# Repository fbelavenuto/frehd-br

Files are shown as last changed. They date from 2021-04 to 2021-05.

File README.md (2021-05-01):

# TRS-80 FreHD BR version

### English

FreHD is a HD emulator for TRS-80 classic computer.

This board is my version made in Cadsoft Eagle software. Original project:

http://members.iinet.net.au/~ianmav/trs80/emulator.htm

`FreHD` is the project itself, `CP300_Adapter` is for Brazilian TRS-80 Model III clone

### Português

FreHD é um emulador de HD para computadores TRS-80.

Estas placas são uma versão minha feito no software Autodesk Eagle. Projeto original:

http://members.iinet.net.au/~ianmav/trs80/emulator.htm

`FreHD` é o projeto em si, `CP300_Adapter` é para o clone brasileiro TRS-80 model III.

Este projeto utiliza um microcontrolador PIC que deve ser gravado com o firmware do arquivo `FreHD_213.hex` e utiliza um circuito integrado de lógica programável (GAL) que deve ser gravado com o arquivo `gal16v8.jed`.

Para o clone CP500 é necessário a regravação da EPROM interna ou troca com o conteúdo do arquivo `CP500_FreHD.rom`.

Para o CP300 é necessário a construção do adaptador que contém uma EPROM que deve ser gravada com o conteúdo do arquivo `FreHD(3000).bin`. A EPROM utilizada é a 2732 que tem espaço para 4KBytes de dados, por ser mais fácil de se encontrar. O arquivo contém somente 2KBytes de dados e deve ser gravado no começo da EPROM (offset 0) deixando o restante da EPROM sem conteúdo.

A lista de material pode ser encontrada em formato Markdown na pasta *Doc* de cada projeto.

É necessário a confecção de um cabo multivias com 50 vias/conector 2x25 para ligação entre o FreHD e Micro (ou Adaptador) e um cabo multivias de 34 vias/conector 2x17 para a ligação do adaptador no CP300. O cabo de 50 vias pode ser aproveitado de antigos cabos SCSI e para o cabo de 34 vias pode ser aproveitado cabos de floppy sem a torção.

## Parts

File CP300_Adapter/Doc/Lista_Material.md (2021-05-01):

# Lista de material

## Resistores

Todos são de 1/4W

| Qtde | Valor |
|:----:|---|
| 3 | 220Ω |
| 5 | 330Ω |
| 5 | 4K7 |
| 5 | 10K |

## Capacitores

| Qtde | Valor | Tipo | Obs |
|:----:|---|---|-----|
|  2 | 22p | Cerâmico | |
|  3 | 100n | Cerâmico | |
|  5 | 1u/16V  | Eletrolítico | Necessário somente se for utilizar a porta RS-232 |
|  2 | 10u/10V | Eletrolítico | |

## LEDs

| Qtde | Valor |
|:----:|---|
| 1 | 3mm Vermelho |
| 1 | 3mm Verde |

## Transistores

| Qtde | Valor |
|:----:|---|
| 1 | BS170 |

## Circuitos Integrados

Todos os CIs tem emcapsulamento DIP

| Qtde | Valor | Obs |
|:----:|---|-----|
| 1 | PIC18F4680 | Gravar com arquivo [HEX](FreHD_213.hex) |
| 1 | GAL16V8 | Gravar com arquivo [JED](gal16v8.jed) |
| 1 | 74HCT245 | |
| 1 | 74HCT595 | |
| 1 | MAX232 | Necessário somente se for utilizar a porta RS-232 |
| 1 | DS1307 | |
| 1 | LP2950-3V3 | |

## Soquetes (opcional)

| Qtde | Tipo |
|:----:|---|
| 1 | 40 pinos |
| 2 | 20 pinos |
| 2 | 16 pinos |
| 1 | 4 pinos |

## Cristais

| Qtde | Valor | Encapsulamento |
|:----:|---|---|
| 1 | 32,768KHz | TC26V |
| 1 | 10Mhz | HC49U-V |

## Diversos

| Qtde | Valor | Modelo |
|:----:|---|---|
| 1 | Conector Mini-USB (tipo B) | |
| 1 | Conector Pinheader macho 2x25 | |
| 2 | Conector Pinheader macho 1x5 | |
| 1 | Conector para bateria CR2032 | |
| 1 | Conector SD ou micro-SD | |

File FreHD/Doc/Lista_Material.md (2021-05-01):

# Lista de material

## Capacitores

| Qtde | Valor | Tipo |
|:----:|---|---|
|  2 | 100n | Cerâmico |

## Circuitos Integrados

Todos os CIs tem emcapsulamento DIP

| Qtde | Valor | Obs |
|:----:|---|-----|
| 1 | EPROM 2732 | Gravar com arquivo [BIN](FreHD(3000).bin) |
| 1 | 74LS04 | |
## Soquetes (opcional)

| Qtde | Tipo |
|:----:|---|
| 1 | 24 pinos (largo) |
| 1 | 14 pinos |

## Diversos

| Qtde | Valor | Modelo |
|:----:|---|---|
| 1 | Conector Pinheader macho 2x25 | |
| 1 | Conector Pinheader macho 2x17 | |

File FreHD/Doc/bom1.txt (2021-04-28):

Part Value       Device          Package      Description

U1   PIC18F4620  PIC18F4680      PDIP-40
U2   GAL16V8     ATF16V8BP3      DIL20        High perfomance CMOS (electrically erasable) programmable logic device (PLD)
U3   74HCT245N   74HCT245N       DIL20        Octal BUS TRANSCEIVER, 3-state
U5   MAX232      MAX232PTH       DIL16        RS232 Transceiver
U6   74HC595N    74HC595N        DIL16        8-bit SHIFT REGISTER, output latch
U7   DS1307      DS1307          DIL08        DS1307
IC1  LP2950-3V3  LP2950Z         TO92         100 mA, Low Power Low Dropout Voltage Regulator
Q1   BS170       BS170           SOT54E       N-CHANNEL MOS FET
J1   MICROSD     MICROSD         MICROSD      Micro SD Socket (optional)
J2   SDMMC06132  SDMMC06132      06132        SD MMC Card holder
XT1  32.768KHz   CRYSTALTC26V    TC26V        CRYSTAL
XT2  10MHz       CRYSTALHC49U-V  HC49U-V      CRYSTAL
B1   CR2032H     CR2032H         CR2032H      LI BATTERY Varta
C1   100n        C-EU050-024X044 C050-024X044 CAPACITOR, European symbol
C2   22p         C-EU050-024X044 C050-024X044 CAPACITOR, European symbol
C3   22p         C-EU050-024X044 C050-024X044 CAPACITOR, European symbol
C4   100n        C-EU050-024X044 C050-024X044 CAPACITOR, European symbol
C5   10u         CPOL-EUE2-4     E2-4         POLARIZED CAPACITOR, European symbol
C6   1u          CPOL-EUE2-4     E2-4         POLARIZED CAPACITOR, European symbol
C7   1u          CPOL-EUE2-4     E2-4         POLARIZED CAPACITOR, European symbol
C8   1u          CPOL-EUE2-4     E2-4         POLARIZED CAPACITOR, European symbol
C9   100n        C-EU050-024X044 C050-024X044 CAPACITOR, European symbol
C10  1u          CPOL-EUE2-4     E2-4         POLARIZED CAPACITOR, European symbol
C11  1u          CPOL-EUE2-4     E2-4         POLARIZED CAPACITOR, European symbol
C12  10u         CPOL-EUE2-4     E2-4         POLARIZED CAPACITOR, European symbol
R1   4K7         R-EU_0207/10    0207/10      RESISTOR, European symbol
R2   10K         R-EU_0207/10    0207/10      RESISTOR, European symbol
R3   4K7         R-EU_0207/10    0207/10      RESISTOR, European symbol
R4   10K         R-EU_0207/10    0207/10      RESISTOR, European symbol
R5   10K         R-EU_0207/10    0207/10      RESISTOR, European symbol
R6   330         R-EU_0207/10    0207/10      RESISTOR, European symbol
R7   220         R-EU_0207/10    0207/10      RESISTOR, European symbol
R8   330         R-EU_0207/10    0207/10      RESISTOR, European symbol
R9   220         R-EU_0207/10    0207/10      RESISTOR, European symbol
R10  220         R-EU_0207/10    0207/10      RESISTOR, European symbol
R11  330         R-EU_0207/10    0207/10      RESISTOR, European symbol
R12  10K         R-EU_0207/10    0207/10      RESISTOR, European symbol
R13  330         R-EU_0207/10    0207/10      RESISTOR, European symbol
R14  330         R-EU_0207/10    0207/10      RESISTOR, European symbol
R15  10K         R-EU_0207/10    0207/10      RESISTOR, European symbol
R16  4K7         R-EU_0207/10    0207/10      RESISTOR, European symbol
R17  4K7         R-EU_0207/10    0207/10      RESISTOR, European symbol
R18  4K7         R-EU_0207/10    0207/10      RESISTOR, European symbol
X1   MUSB-B      MiniUSB type B  M-USB B      Mini USB type B connector
JP1  BUS         PINHD-2X25      2X25         PIN HEADER
SV1  Serial      MA05-1          MA05-1       PIN HEADER
SV2  ICSP        MA05-1          MA05-1       PIN HEADER
LED1 VM          LED3MM          LED3MM       LED Red 3mm
LED2 VD          LED3MM          LED3MM       LED Green 3mm

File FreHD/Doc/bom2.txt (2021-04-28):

Qty Value       Device          Package      Parts                 Description

1   PIC18F4620  PIC18F4680      PDIP-40      U1
1   GAL16V8     ATF16V8BP3      DIL20        U2                    High perfomance CMOS (electrically erasable) programmable logic device (PLD)
1   74HCT245N   74HCT245N       DIL20        U3                    Octal BUS TRANSCEIVER, 3-state
1   MAX232      MAX232PTH       DIL16        U5                    RS232 Transceiver
1   74HC595N    74HC595N        DIL16        U6                    8-bit SHIFT REGISTER, output latch
1   DS1307      DS1307          DIL08        U7                    DS1307
1   LP2950-3V3  LP2950Z         TO92         IC1                   100 mA, Low Power Low Dropout Voltage Regulator
1   BS170       BS170           SOT54E       Q1                    N-CHANNEL MOS FET
1   MICROSD     MICROSD         MICROSD      J1                    Micro SD Socket (optional)
1   SDMMC06132  SDMMC06132      06132        J2                    SD MMC Card holder
1   32.768KHz   CRYSTALTC26V    TC26V        XT1                   CRYSTAL
1   10MHz       CRYSTALHC49U-V  HC49U-V      XT2                   CRYSTAL
1   CR2032H     CR2032H         CR2032H      B1                    LI BATTERY Varta
3   100n        C-EU050-024X044 C050-024X044 C1, C4, C9            CAPACITOR, European symbol
2   22p         C-EU050-024X044 C050-024X044 C2, C3                CAPACITOR, European symbol
2   10u         CPOL-EUE2-4     E2-4         C5, C12               POLARIZED CAPACITOR, European symbol
5   1u          CPOL-EUE2-4     E2-4         C6, C7, C8, C10, C11  POLARIZED CAPACITOR, European symbol
5   4K7         R-EU_0207/10    0207/10      R1, R3, R16, R17, R18 RESISTOR, European symbol
5   10K         R-EU_0207/10    0207/10      R2, R4, R5, R12, R15  RESISTOR, European symbol
5   330         R-EU_0207/10    0207/10      R6, R8, R11, R13, R14 RESISTOR, European symbol
3   220         R-EU_0207/10    0207/10      R7, R9, R10           RESISTOR, European symbol
1   MUSB-B      MiniUSB type B  M-USB B      X1                    Mini USB type B connector
1   BUS         PINHD-2X25      2X25         JP1                   PIN HEADER
1   ICSP        MA05-1          MA05-1       SV2                   PIN HEADER
1   Serial      MA05-1          MA05-1       SV1                   PIN HEADER
1   VM          LED3MM          LED3MM       LED1                  LED Red 3mm
1   VD          LED3MM          LED3MM       LED2                  LED Green 3mm

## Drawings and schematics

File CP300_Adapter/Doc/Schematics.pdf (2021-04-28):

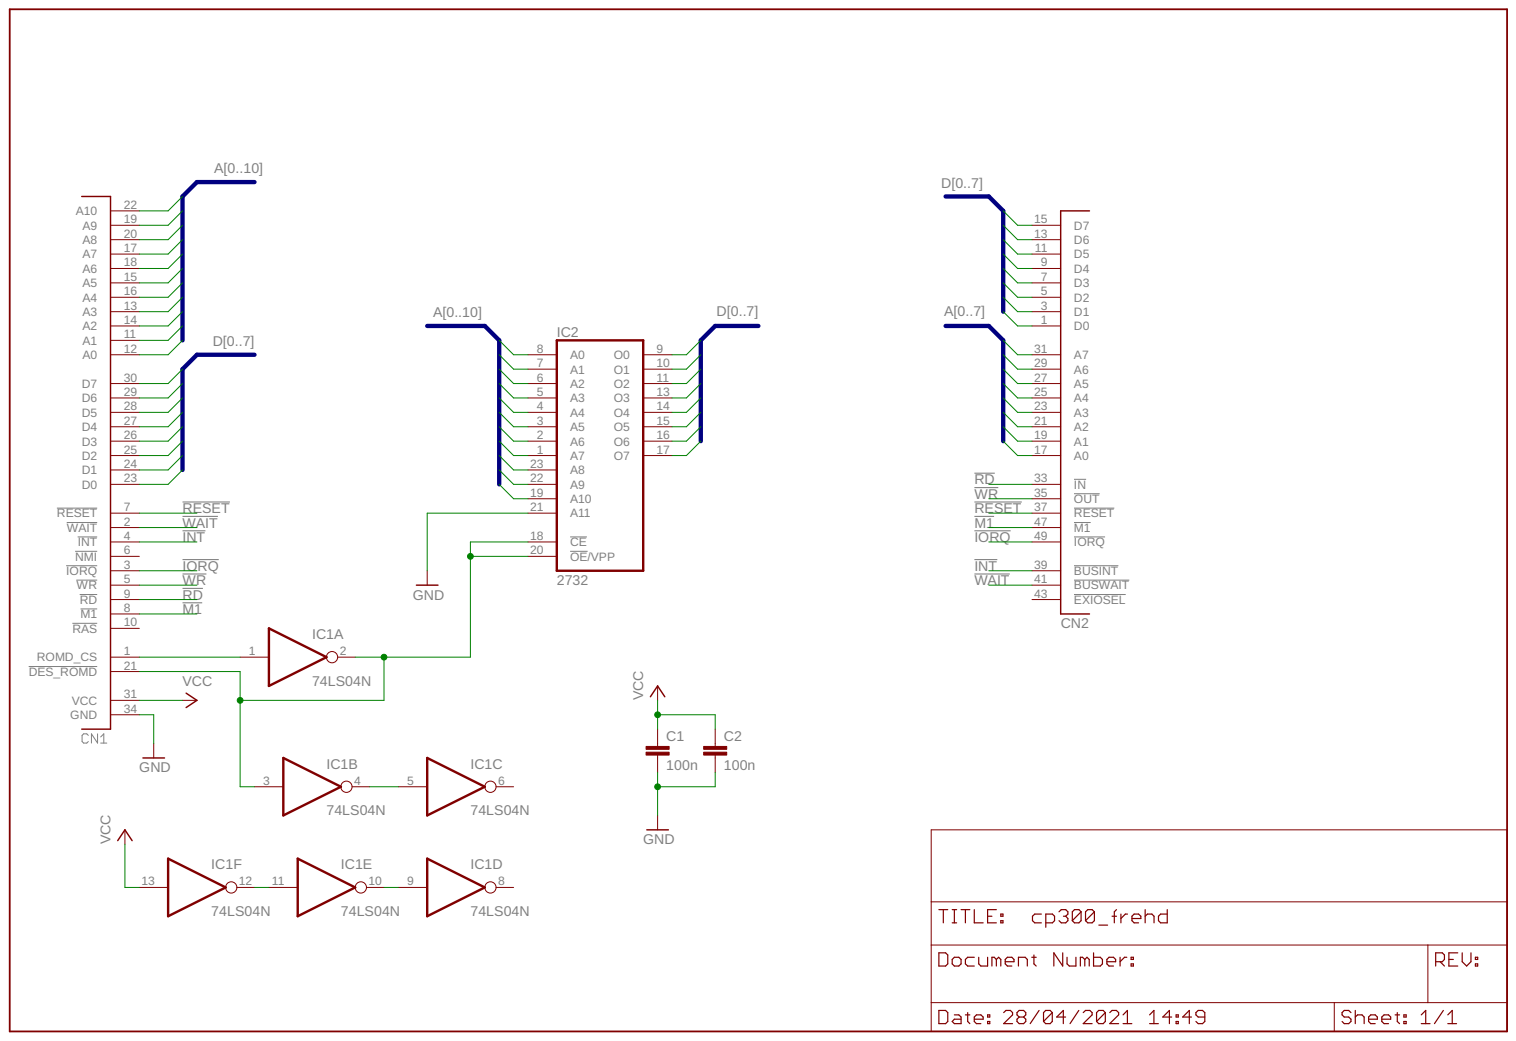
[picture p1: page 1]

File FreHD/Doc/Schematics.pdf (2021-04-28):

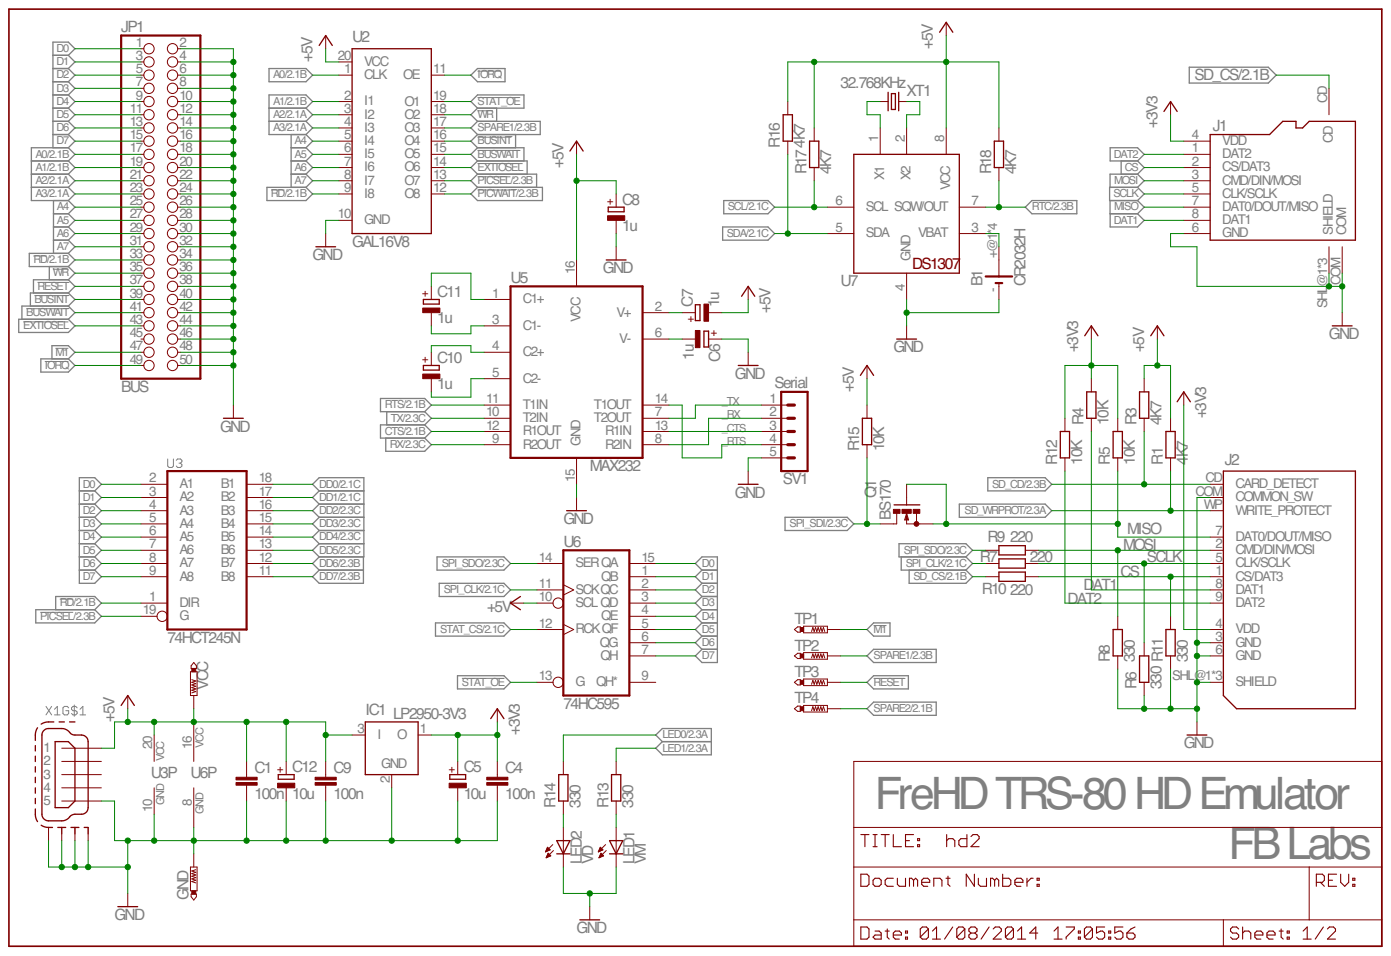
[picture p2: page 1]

13 | 3 _CTS

_RTS 4

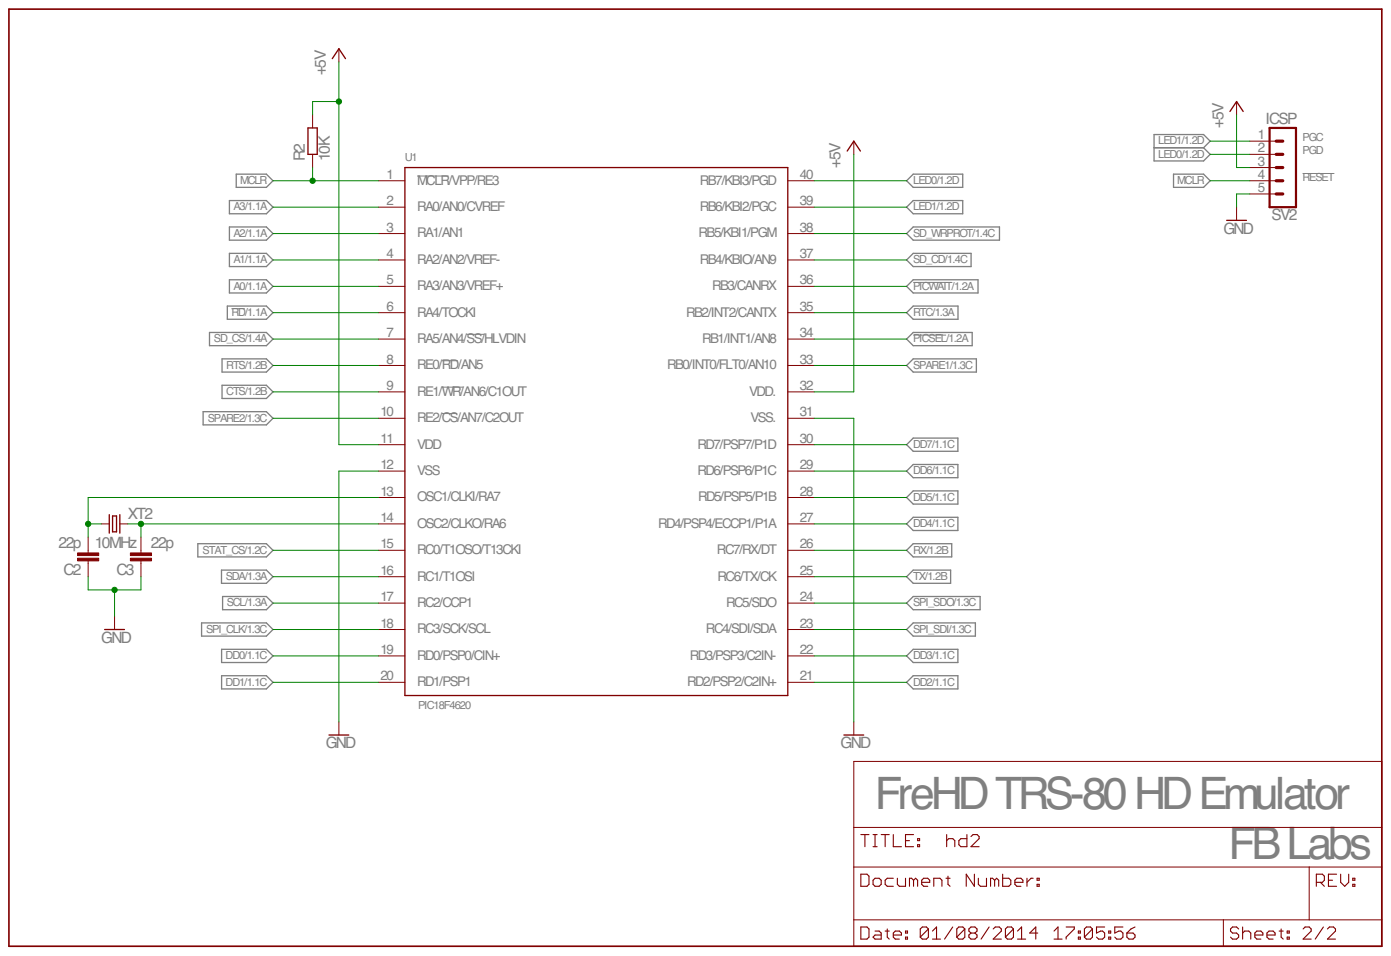
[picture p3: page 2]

RC0/T1OSO/T13CKI 15 RC1/T1OSI 16 | 26

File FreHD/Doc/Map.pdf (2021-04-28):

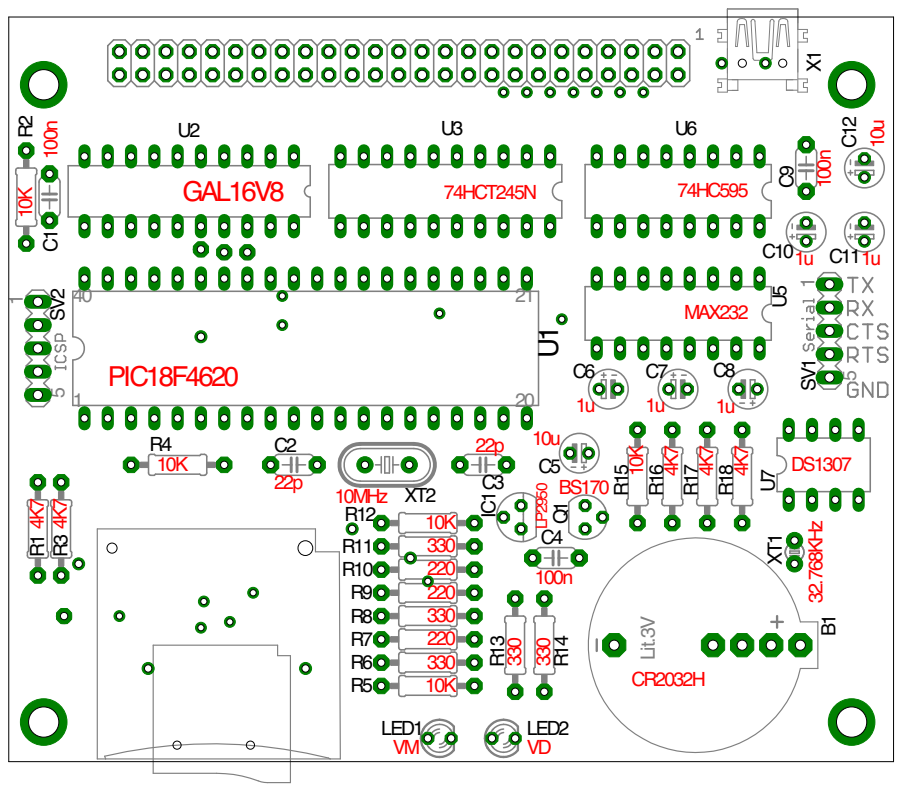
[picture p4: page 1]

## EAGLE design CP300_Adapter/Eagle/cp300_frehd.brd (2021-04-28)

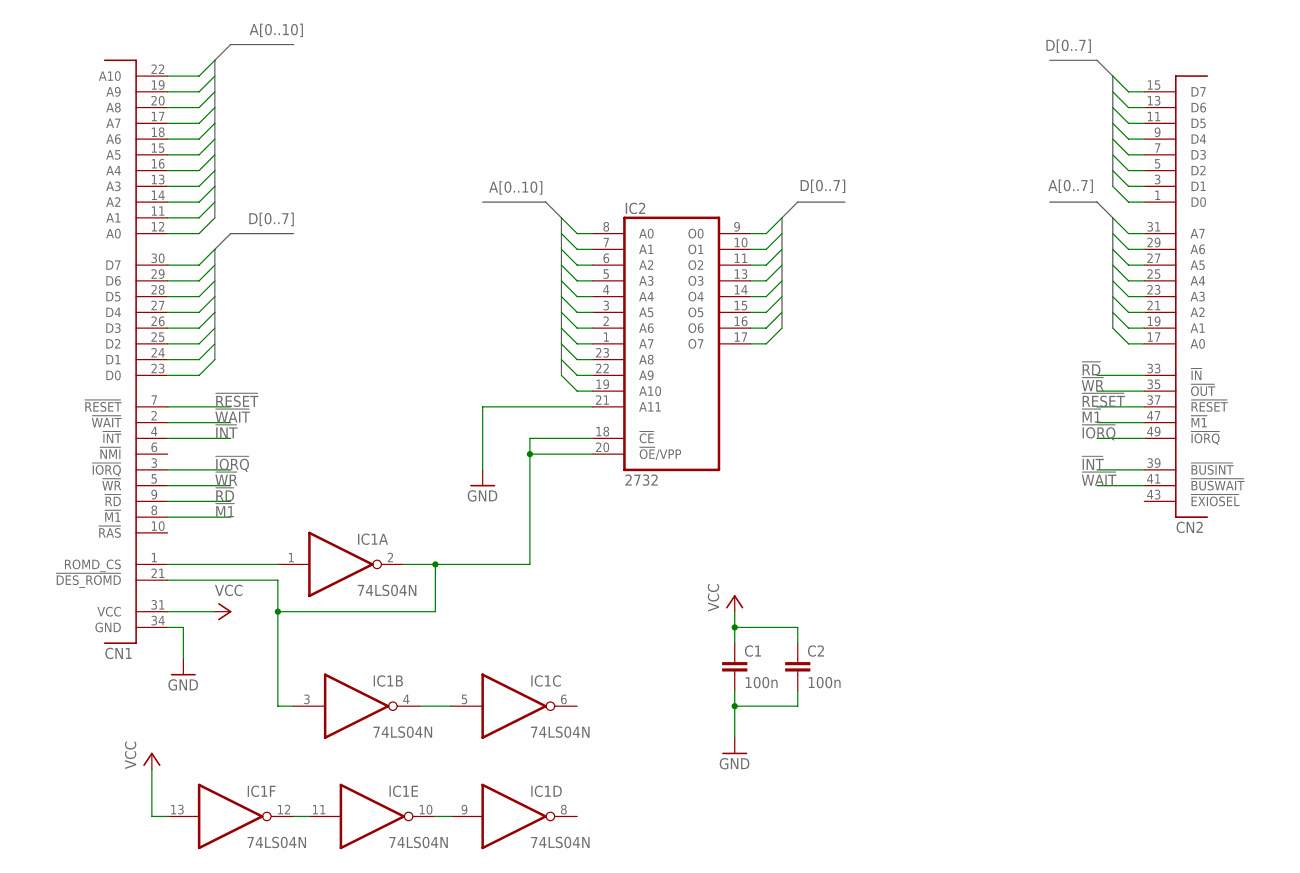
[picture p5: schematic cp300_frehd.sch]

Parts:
C1, C2: 100n; C050-024X044
CN1: CP300_EXPA; 2X17
CN2: TRS80_EXPA; 2X25
IC1: 74LS04N; DIL14
IC2: 2732; DIL24

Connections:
!INT: CN1.4 (!INT), CN2.39 (!BUSINT)
!IORQ: CN1.3 (!IORQ), CN2.49 (!IORQ)
!M1: CN1.8 (!M1), CN2.47 (!M1)
!RD: CN1.9 (!RD), CN2.33 (!IN)
!RESET: CN1.7 (!RESET), CN2.37 (!RESET)
!WAIT: CN1.2 (!WAIT), CN2.41 (!BUSWAIT)
!WR: CN1.5 (!WR), CN2.35 (!OUT)
A0: CN1.12 (A0), CN2.17 (A0), IC2.8 (A0)
A1: CN1.11 (A1), CN2.19 (A1), IC2.7 (A1)
A2: CN1.14 (A2), CN2.21 (A2), IC2.6 (A2)
A3: CN1.13 (A3), CN2.23 (A3), IC2.5 (A3)
A4: CN1.16 (A4), CN2.25 (A4), IC2.4 (A4)
A5: CN1.15 (A5), CN2.27 (A5), CN2.29 (A6), IC2.3 (A5)
A6: CN1.18 (A6), IC2.2 (A6)
A7: CN1.17 (A7), CN2.31 (A7), IC2.1 (A7)
A8: CN1.20 (A8), IC2.23 (A8)
A9: CN1.19 (A9), IC2.22 (A9)
A10: CN1.22 (A10), IC2.19 (A10)
D0: CN1.23 (D0), CN2.1 (D0), IC2.9 (O0)
D1: CN1.24 (D1), CN2.3 (D1), IC2.10 (O1)
D2: CN1.25 (D2), CN2.5 (D2), IC2.11 (O2)
D3: CN1.26 (D3), CN2.7 (D3), IC2.13 (O3)
D4: CN1.27 (D4), CN2.9 (D4), IC2.14 (O4)
D5: CN1.28 (D5), CN2.11 (D5), IC2.15 (O5)
D6: CN1.29 (D6), CN2.13 (D6), IC2.16 (O6)
D7: CN1.30 (D7), CN2.15 (D7), IC2.17 (O7)
GND: C1.2, C2.2, CN1.34 (GND), CN2.2 (GND), CN2.4 (GND), CN2.6 (GND), CN2.8 (GND), CN2.10 (GND), CN2.12 (GND), CN2.14 (GND), CN2.16 (GND), CN2.18 (GND), CN2.20 (GND), CN2.22 (GND), CN2.24 (GND), CN2.26 (GND), CN2.28 (GND), CN2.30 (GND), CN2.32 (GND), CN2.34 (GND), CN2.36 (GND), CN2.38 (GND), CN2.40 (GND), CN2.42 (GND), CN2.44 (GND), CN2.46 (GND), CN2.48 (GND), CN2.50 (GND), IC1.7 (GND), IC2.12 (GND), IC2.21 (A11)
unnamed: IC1.11 (I), IC1.12 (O)
unnamed: IC1.9 (I), IC1.10 (O)
unnamed: IC1.4 (O), IC1.5 (I)
unnamed: CN1.1 (ROMD_CS), IC1.1 (I)
unnamed: CN1.21 (!DES_ROMD), IC1.2 (O), IC1.3 (I), IC2.18 (!CE), IC2.20 (!OE!/VPP)
VCC: C1.1, C2.1, CN1.31 (VCC), IC1.13 (I), IC1.14 (VCC), IC2.24 (VCC)

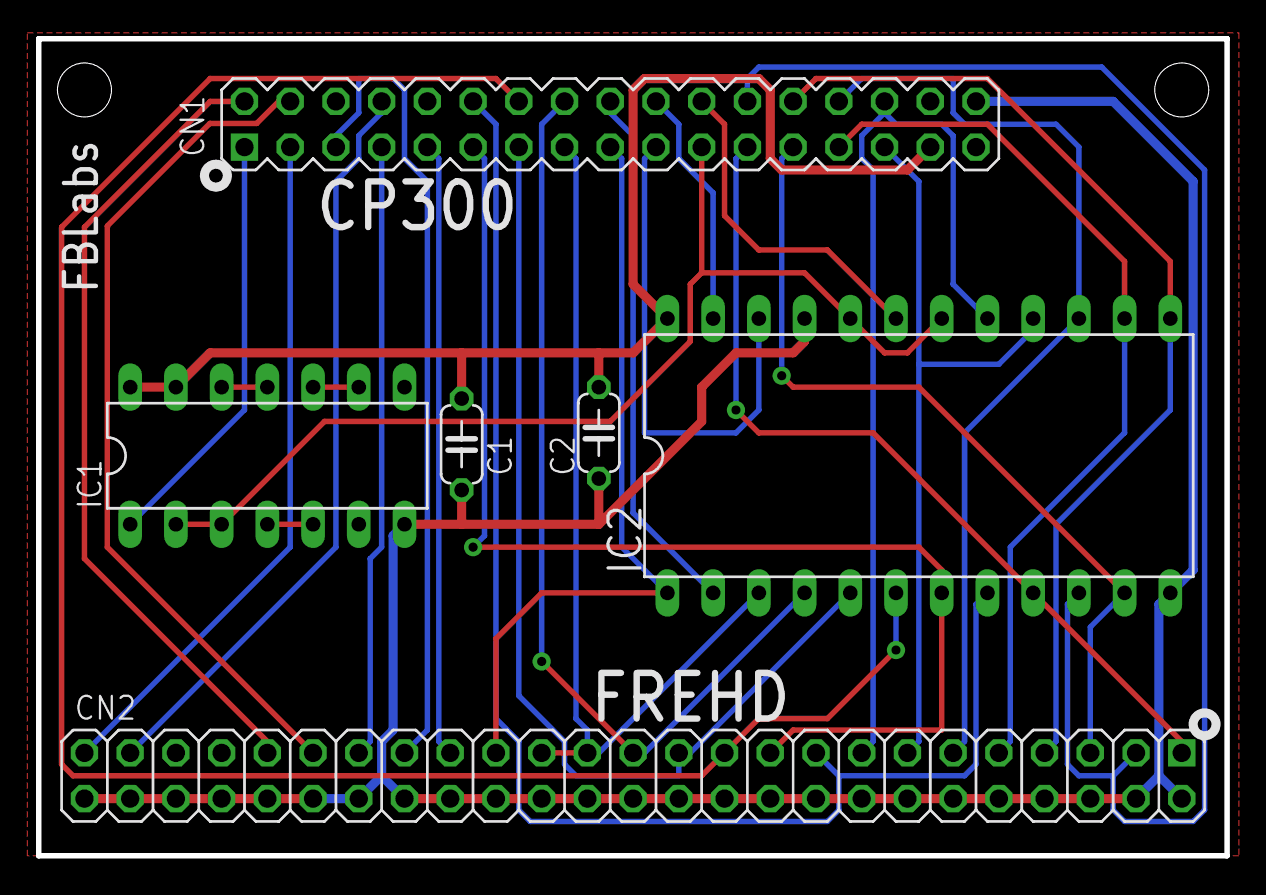
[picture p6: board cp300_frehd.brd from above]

Board: 2 copper layers, 66.0 x 45.4 mm, 6 parts (0 on the bottom side), 33 nets.

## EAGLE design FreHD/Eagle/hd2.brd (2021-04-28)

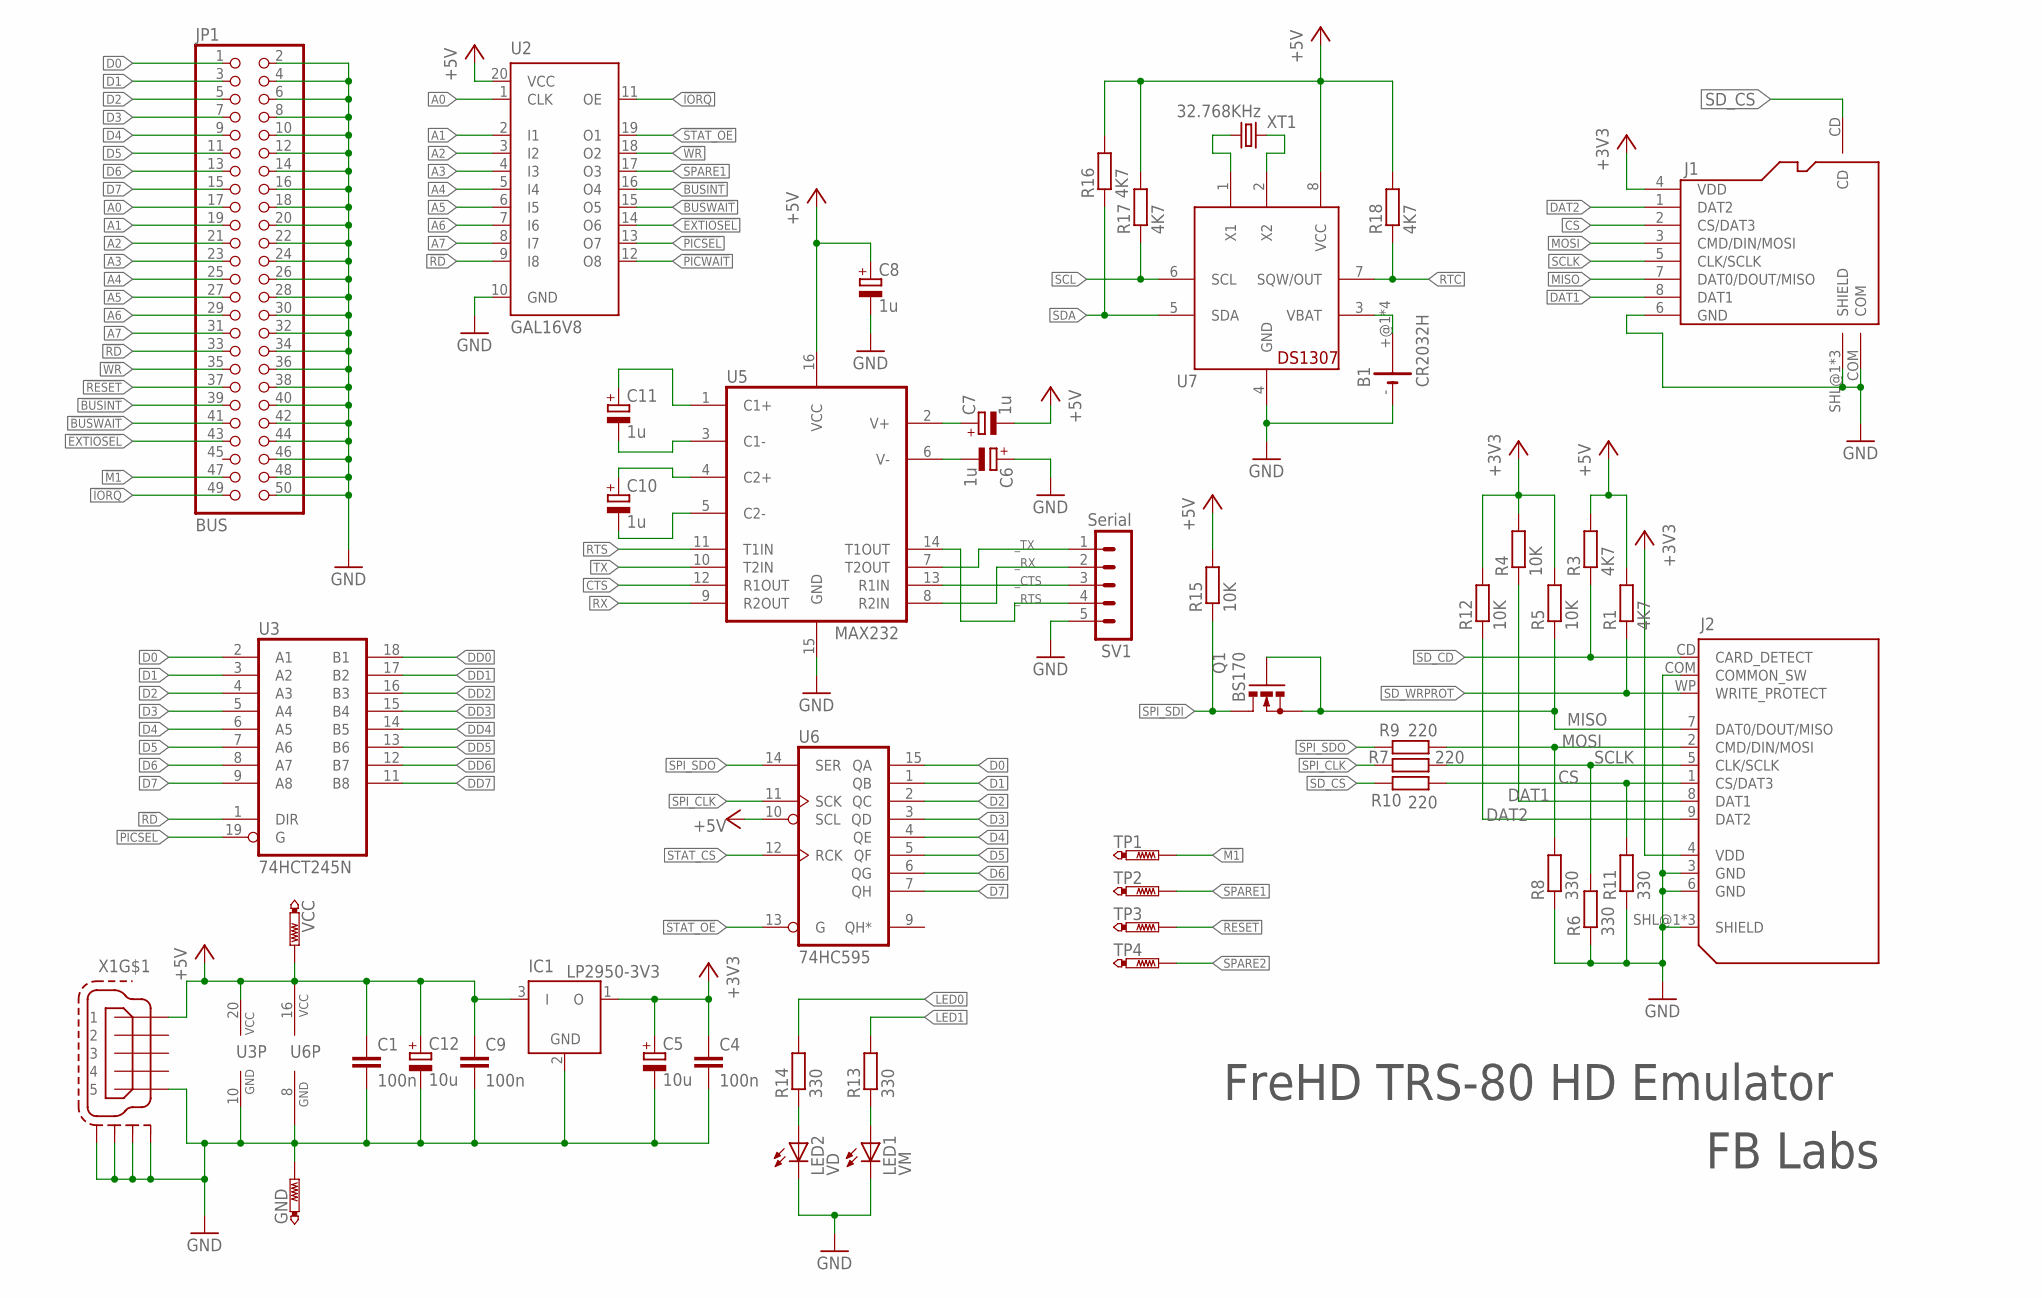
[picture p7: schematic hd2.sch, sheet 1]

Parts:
B1: CR2032H
C1, C4, C9: 100n; C050-024X044
C5, C12: 10u; E2-4
C6, C7, C8, C10, C11: 1u; E2-4
GND: PTR1B2,54; B2,54
IC1: LP2950-3V3; TO92
J1: MICROSD-9P; 9P-SMD-W/-RING
J2: SDMMC06132; 06132
JP1: BUS; 2X25
LED1: VM; LED3MM
LED2: VD; LED3MM
Q1: BS170; SOT54E
R1, R3, R16, R17, R18: 4K7; 0207/10
R4, R5, R12, R15: 10K; 0207/10
R6, R8, R11, R13, R14: 330; 0207/10
R7, R9, R10: 220; 0207/10
SV1: Serial; MA05-1
TP1, TP2, TP3, TP4: PTR1PAD1-10; P1-10
U2: GAL16V8; DIL20
U3: 74HCT245N; DIL20
U5: MAX232; DIL16
U6: 74HC595; DIL16
U7: DS1307; DIL08
VCC: PTR1B2,54; B2,54
X1: MINI-USB-SCHIELD-32005-301; 32005-301
XT1: 32.768KHz; TC26V

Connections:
!BUSINT: JP1.39, U2.16 (O4)
!BUSWAIT: JP1.41, U2.15 (O5)
!EXTIOSEL: JP1.43, U2.14 (O6)
!IORQ: JP1.49, U2.11 (OE)
!M1: JP1.47, TP1.TP
!PICSEL: U2.13 (O7), U3.19 (G); also elsewhere on the board
!PICWAIT: U2.12 (O8); also elsewhere on the board
!RD: JP1.33, U2.9 (I8), U3.1 (DIR); also elsewhere on the board
!RESET: JP1.37, TP3.TP
!STAT_OE: U2.19 (O1), U6.13 (G)
!WR: JP1.35, U2.18 (O2)
+3V3: C4.1, C5.+, IC1.1 (O), J1.4 (VDD), J2.4 (VDD), R4.2, R5.2, R12.2
+5V: C1.1, C7.-, C8.+, C9.1, C12.+, IC1.3 (I), R1.2, R3.2, R15.2, R16.2, R17.2, R18.2, U2.20 (VCC), U3.20 (VCC), U5.16 (VCC), U6.10 (SCL), U6.16 (VCC), U7.8 (VCC), VCC.TP, X1.1; also elsewhere on the board
A0: JP1.17, U2.1 (CLK); also elsewhere on the board
A1: JP1.19, U2.2 (I1); also elsewhere on the board
A2: JP1.21, U2.3 (I2); also elsewhere on the board
A3: JP1.23, U2.4 (I3); also elsewhere on the board
A4: JP1.25, U2.5 (I4)
A5: JP1.27, U2.6 (I5)
A6: JP1.29, U2.7 (I6)
A7: JP1.31, U2.8 (I7)
CS: J1.2 (CS/DAT3), J2.1 (CS/DAT3), R10.1, R11.2
CTS: U5.12 (R1OUT); also elsewhere on the board
D0: JP1.1, U3.2 (A1), U6.15 (QA)
D1: JP1.3, U3.3 (A2), U6.1 (QB)
D2: JP1.5, U3.4 (A3), U6.2 (QC)
D3: JP1.7, U3.5 (A4), U6.3 (QD)
D4: JP1.9, U3.6 (A5), U6.4 (QE)
D5: JP1.11, U3.7 (A6), U6.5 (QF)
D6: JP1.13, U3.8 (A7), U6.6 (QG)
D7: JP1.15, U3.9 (A8), U6.7 (QH)
DAT1: J1.8 (DAT1), J2.8 (DAT1), R4.1
DAT2: J1.1 (DAT2), J2.9 (DAT2), R12.1
DD0: U3.18 (B1); also elsewhere on the board
DD1: U3.17 (B2); also elsewhere on the board
DD2: U3.16 (B3); also elsewhere on the board
DD3: U3.15 (B4); also elsewhere on the board
DD4: U3.14 (B5); also elsewhere on the board
DD5: U3.13 (B6); also elsewhere on the board
DD6: U3.12 (B7); also elsewhere on the board
DD7: U3.11 (B8); also elsewhere on the board
GND: B1.-, C1.2, C4.2, C5.-, C6.+, C8.-, C9.2, C12.-, GND.TP, IC1.2 (GND), J1.6 (GND), J1.COM, J1.SHL@1 (SHIELD), J1.SHL@2 (SHIELD), J1.SHL@3 (SHIELD), J2.3 (GND), J2.6 (GND), J2.COM (COMMON_SW), J2.SHL@1 (SHIELD), J2.SHL@2 (SHIELD), J2.SHL@3 (SHIELD), JP1.2, JP1.4, JP1.6, JP1.8, JP1.10, JP1.12, JP1.14, JP1.16, JP1.18, JP1.20, JP1.22, JP1.24, JP1.26, JP1.28, JP1.30, JP1.32, JP1.34, JP1.36, JP1.38, JP1.40, JP1.42, JP1.44, JP1.46, JP1.48, JP1.50, LED1.K (C), LED2.K (C), R6.1, R8.1, R11.1, SV1.5, U2.10 (GND), U3.10 (GND), U5.15 (GND), U6.8 (GND), U7.4 (GND), X1.5, X1.M1 (S1), X1.M2 (S2), X1.M3 (S3), X1.M4 (S4); also elsewhere on the board
LED0: R14.2; also elsewhere on the board
LED1: R13.2; also elsewhere on the board
MISO: J1.7 (DAT0/DOUT/MISO), J2.7 (DAT0/DOUT/MISO), Q1.G, Q1.S, R5.1
MOSI: J1.3 (CMD/DIN/MOSI), J2.2 (CMD/DIN/MOSI), R8.2, R9.1
unnamed: U7.1 (X1), XT1.1
unnamed: U7.2 (X2), XT1.2
unnamed: C6.-, U5.6 (V-)
unnamed: C7.+, U5.2 (V+)
unnamed: B1.+@1 (+), B1.+@2 (+), B1.+@3 (+), B1.+@4 (+), U7.3 (VBAT)
unnamed: C11.-, U5.3 (C1-)
unnamed: C11.+, U5.1 (C1+)
unnamed: C10.+, U5.4 (C2+)
unnamed: C10.-, U5.5 (C2-)
unnamed: LED2.A, R14.1
unnamed: LED1.A, R13.1
RTC: R18.1, U7.7 (SQW/OUT); also elsewhere on the board
RTS: U5.11 (T1IN); also elsewhere on the board
RX: U5.9 (R2OUT); also elsewhere on the board
SCL: R17.1, U7.6 (SCL); also elsewhere on the board
SCLK: J1.5 (CLK/SCLK), J2.5 (CLK/SCLK), R6.2, R7.1
SDA: R16.1, U7.5 (SDA); also elsewhere on the board
SD_CD: J2.CD (CARD_DETECT), R3.1; also elsewhere on the board
SD_CS: J1.CD, R10.2; also elsewhere on the board
SD_WRPROT: J2.WP (WRITE_PROTECT), R1.1; also elsewhere on the board
SPARE1: TP2.TP, U2.17 (O3); also elsewhere on the board
SPARE2: TP4.TP; also elsewhere on the board
SPI_CLK: R7.2, U6.11 (SCK); also elsewhere on the board
SPI_SDI: Q1.D, R15.1; also elsewhere on the board
SPI_SDO: R9.2, U6.14 (SER); also elsewhere on the board
STAT_CS: U6.12 (RCK); also elsewhere on the board
TX: U5.10 (T2IN); also elsewhere on the board
_CTS: SV1.3, U5.13 (R1IN)
_RTS: SV1.4, U5.14 (T1OUT)
_RX: SV1.2, U5.8 (R2IN)
_TX: SV1.1, U5.7 (T2OUT)

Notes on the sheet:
FreHD TRS-80 HD Emulator
FB Labs

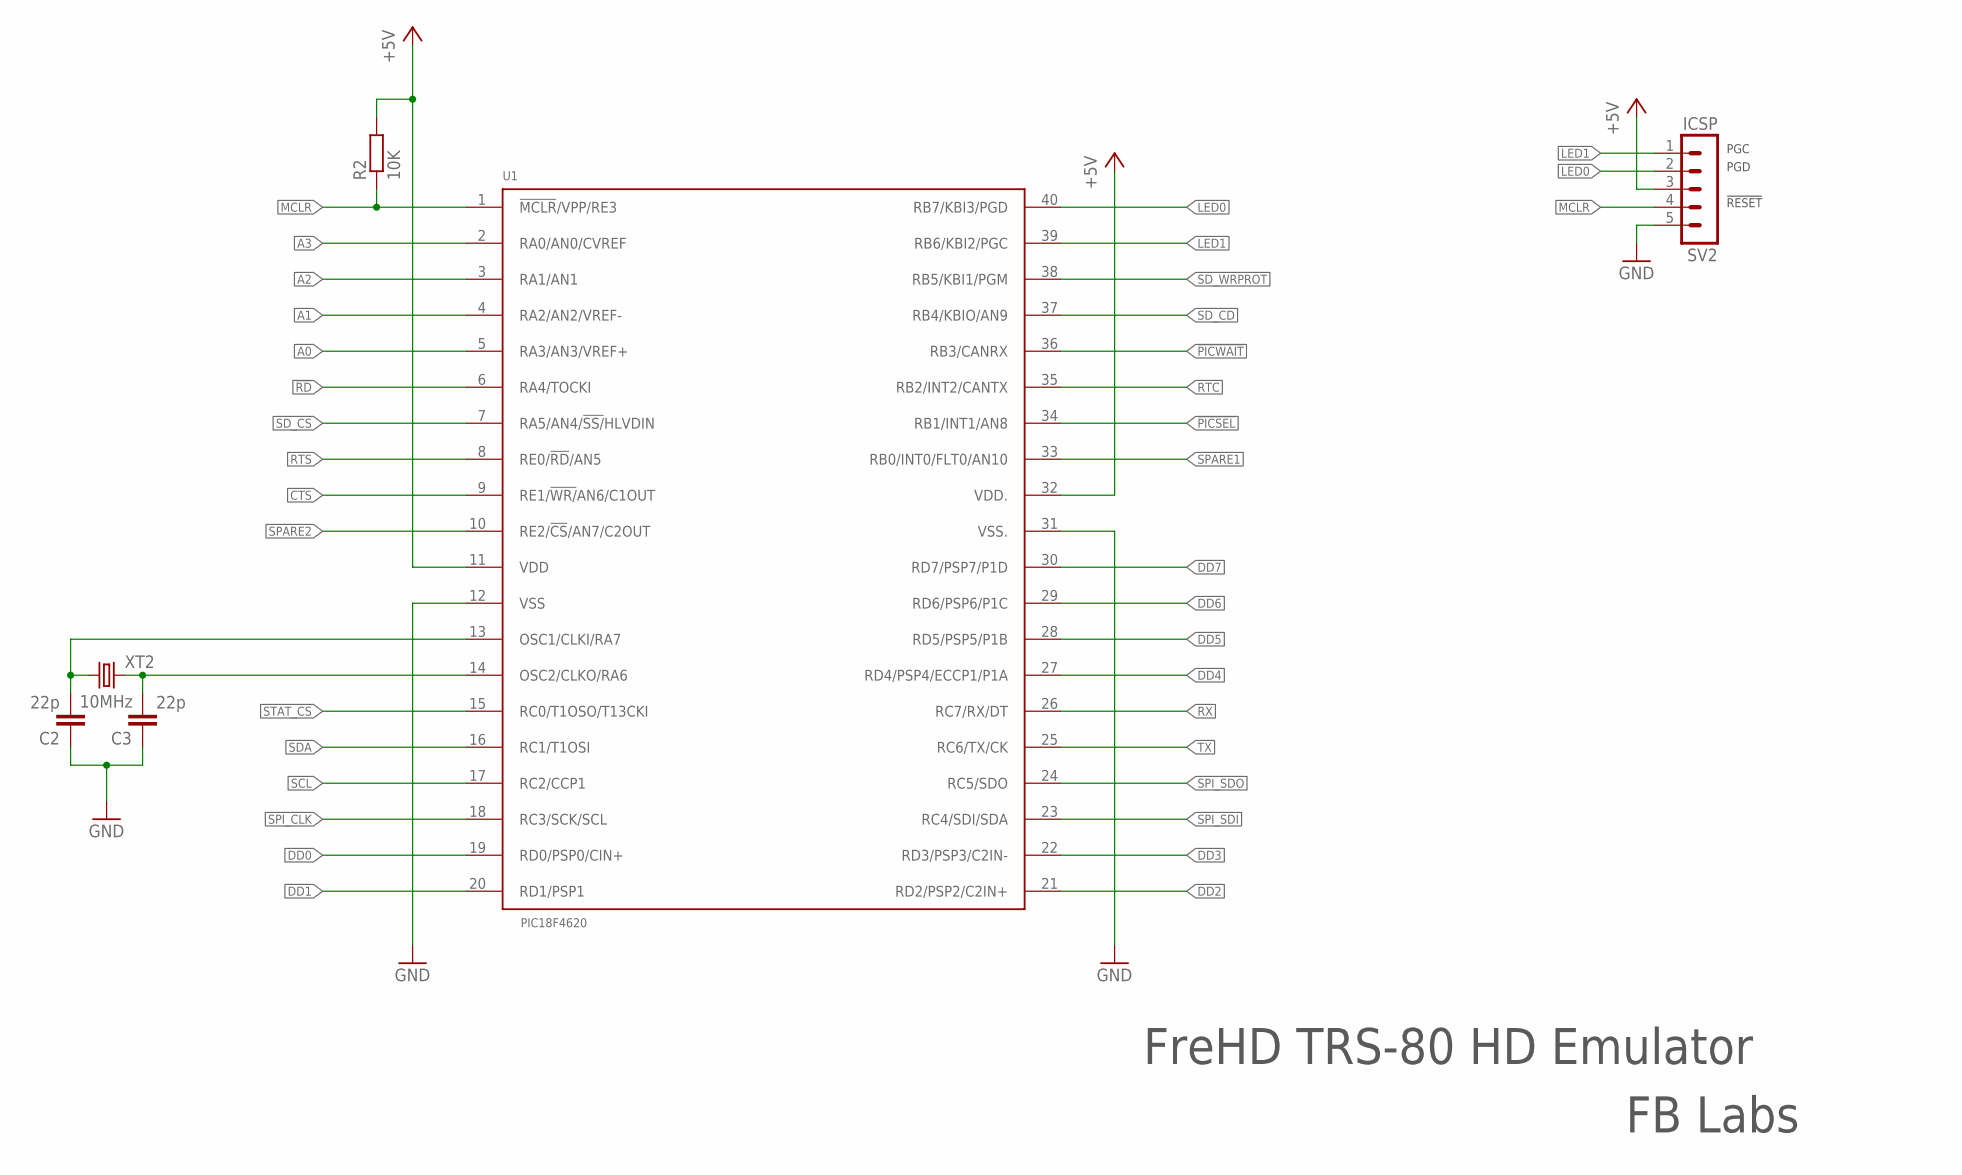
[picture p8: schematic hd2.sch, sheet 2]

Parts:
C2, C3: 22p; C050-024X044
R2: 10K; 0207/10
SV2: ICSP; MA05-1
U1: PIC18F4620; PDIP-40
XT2: 10MHz; HC49U-V

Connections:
!PICSEL: U1.34 (RB1/INT1/AN8); also elsewhere on the board
!PICWAIT: U1.36 (RB3/CANRX); also elsewhere on the board
!RD: U1.6 (RA4/TOCKI); also elsewhere on the board
+5V: R2.2, SV2.3, U1.11 (VDD), U1.32 (VDD.); also elsewhere on the board
A0: U1.5 (RA3/AN3/VREF+); also elsewhere on the board
A1: U1.4 (RA2/AN2/VREF-); also elsewhere on the board
A2: U1.3 (RA1/AN1); also elsewhere on the board
A3: U1.2 (RA0/AN0/CVREF); also elsewhere on the board
CTS: U1.9 (RE1/!WR/!AN6/C1OUT); also elsewhere on the board
DD0: U1.19 (RD0/PSP0/CIN+); also elsewhere on the board
DD1: U1.20 (RD1/PSP1); also elsewhere on the board
DD2: U1.21 (RD2/PSP2/C2IN+); also elsewhere on the board
DD3: U1.22 (RD3/PSP3/C2IN-); also elsewhere on the board
DD4: U1.27 (RD4/PSP4/ECCP1/P1A); also elsewhere on the board
DD5: U1.28 (RD5/PSP5/P1B); also elsewhere on the board
DD6: U1.29 (RD6/PSP6/P1C); also elsewhere on the board
DD7: U1.30 (RD7/PSP7/P1D); also elsewhere on the board
GND: C2.1, C3.1, SV2.5, U1.12 (VSS), U1.31 (VSS.); also elsewhere on the board
LED0: SV2.2, U1.40 (RB7/KBI3/PGD); also elsewhere on the board
LED1: SV2.1, U1.39 (RB6/KBI2/PGC); also elsewhere on the board
MCLR: R2.1, SV2.4, U1.1 (!MCLR!/VPP/RE3)
unnamed: C2.2, U1.13 (OSC1/CLKI/RA7), XT2.1
unnamed: C3.2, U1.14 (OSC2/CLKO/RA6), XT2.2
RTC: U1.35 (RB2/INT2/CANTX); also elsewhere on the board
RTS: U1.8 (RE0/!RD!/AN5); also elsewhere on the board
RX: U1.26 (RC7/RX/DT); also elsewhere on the board
SCL: U1.17 (RC2/CCP1); also elsewhere on the board
SDA: U1.16 (RC1/T1OSI); also elsewhere on the board
SD_CD: U1.37 (RB4/KBIO/AN9); also elsewhere on the board
SD_CS: U1.7 (RA5/AN4/!SS/!HLVDIN); also elsewhere on the board
SD_WRPROT: U1.38 (RB5/KBI1/PGM); also elsewhere on the board
SPARE1: U1.33 (RB0/INT0/FLT0/AN10); also elsewhere on the board
SPARE2: U1.10 (RE2/!CS!/AN7/C2OUT); also elsewhere on the board
SPI_CLK: U1.18 (RC3/SCK/SCL); also elsewhere on the board
SPI_SDI: U1.23 (RC4/SDI/SDA); also elsewhere on the board
SPI_SDO: U1.24 (RC5/SDO); also elsewhere on the board
STAT_CS: U1.15 (RC0/T1OSO/T13CKI); also elsewhere on the board
TX: U1.25 (RC6/TX/CK); also elsewhere on the board

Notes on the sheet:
PGD
PGC
!RESET
FreHD TRS-80 HD Emulator
FB Labs

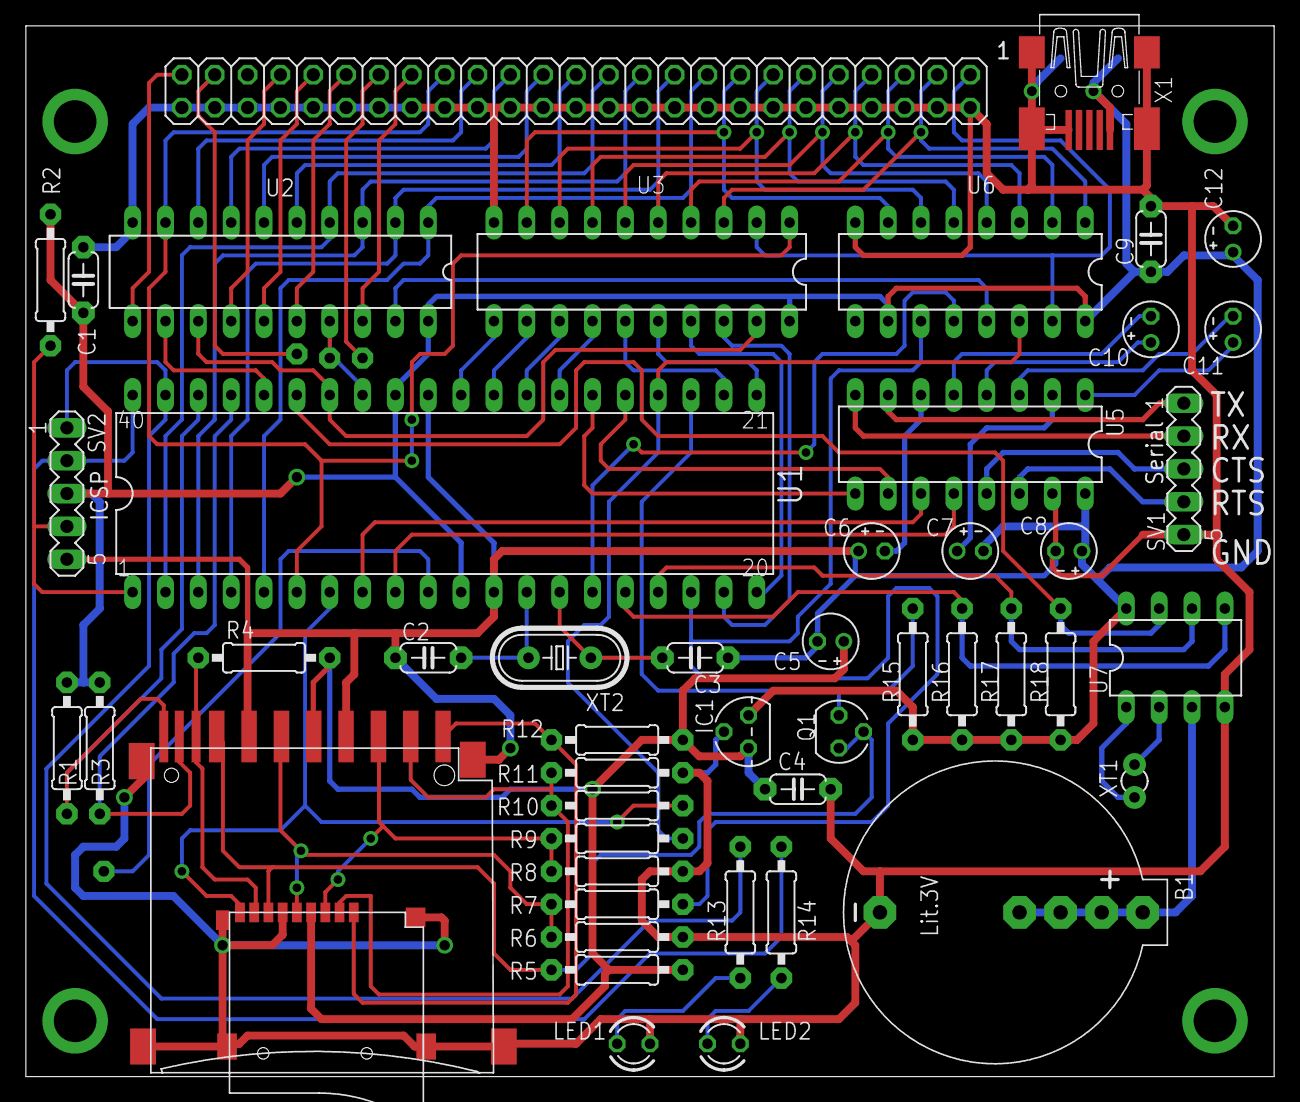
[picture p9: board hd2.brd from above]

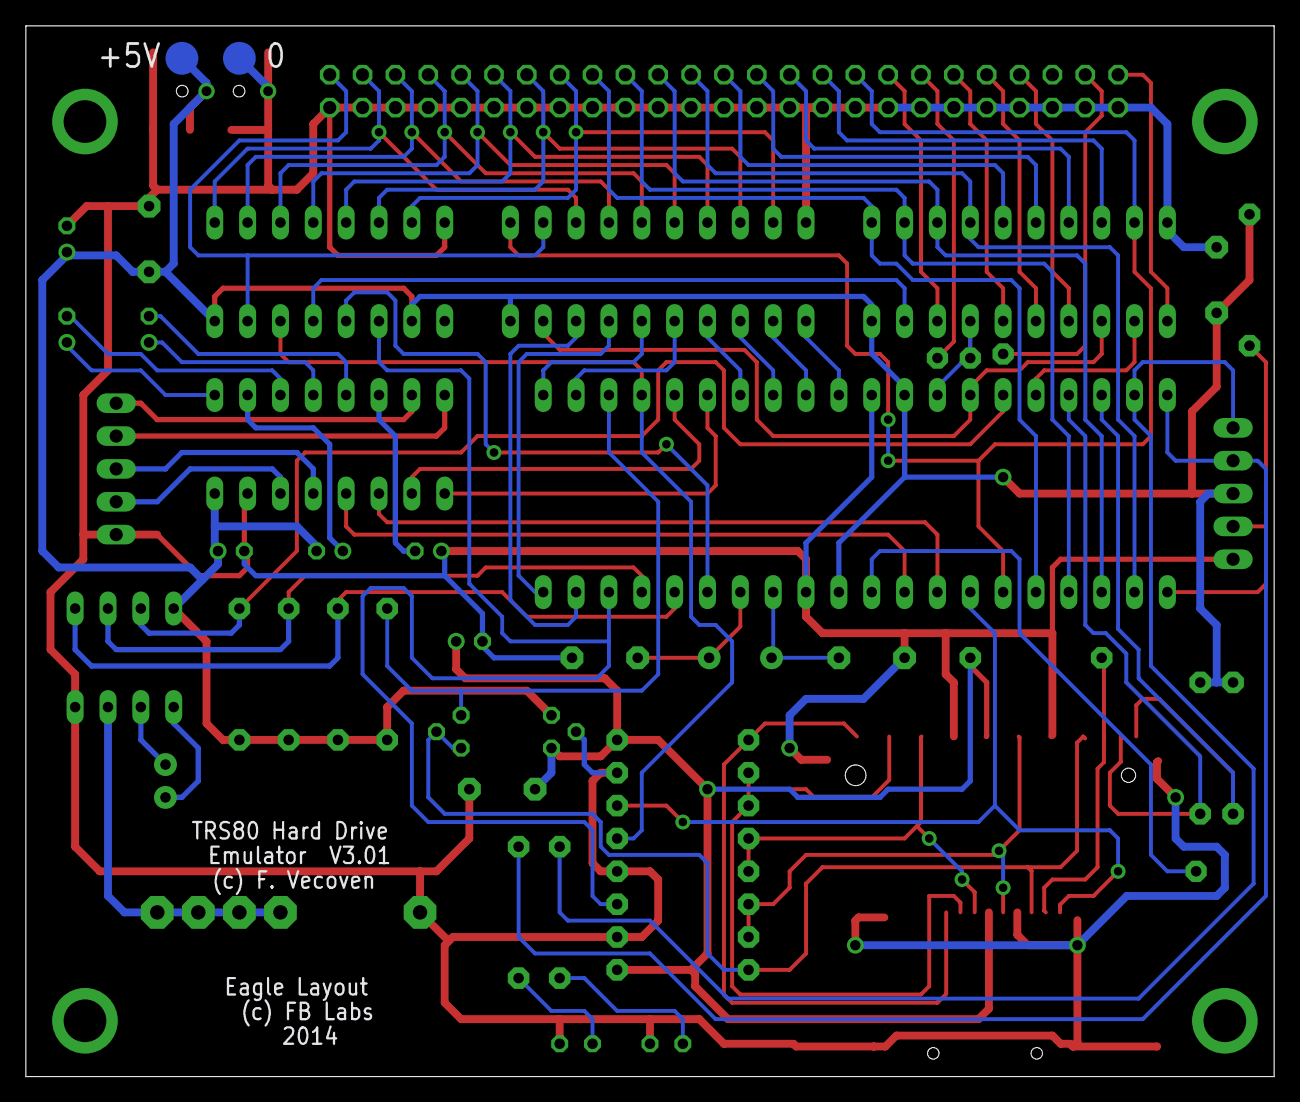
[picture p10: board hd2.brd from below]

Board: 2 copper layers, 96.5 x 81.2 mm, 55 parts (2 on the bottom side), 80 nets.

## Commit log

2021-04-29 Corrigindo gitignore e adicionado arquivos de furação Gerber
    [cp300_frehd.XLN, hd2.XLN]
2021-05-01 Adicionado documentação e lista de materiais

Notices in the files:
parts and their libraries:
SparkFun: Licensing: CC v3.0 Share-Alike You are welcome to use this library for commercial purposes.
